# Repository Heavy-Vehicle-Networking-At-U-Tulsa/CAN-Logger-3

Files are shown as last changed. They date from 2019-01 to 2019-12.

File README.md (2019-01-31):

# CAN-Logger-3

An open source data logging system for heavy vehicle networks.

The docs folder contains schematics, gerber files, and Altium Designer source files. 

## Acknowledgements

This material is based upon work supported by the National Science Foundation under Grant No. 1715409. This project is in collaboration with the National Motor Freight Traffic Association (NMFTA).

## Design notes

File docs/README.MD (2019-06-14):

# CAN Logger 3 Documentation

## Errata
The original bill of materials uses the ATEEC608A-SSHCZ CryptoAuthentication chip from Microchip. This device is a SOIC 8 chip with single wire communicaitons. However, the schematic has the device connected as an I2C device. This chip should be replaced with the ATEEC608A-SSHDA-T device that used I2C communications.

Programmers must use ask for a non-disclosure agreement to get a data sheet for ATECC608A-SSHDA-T.

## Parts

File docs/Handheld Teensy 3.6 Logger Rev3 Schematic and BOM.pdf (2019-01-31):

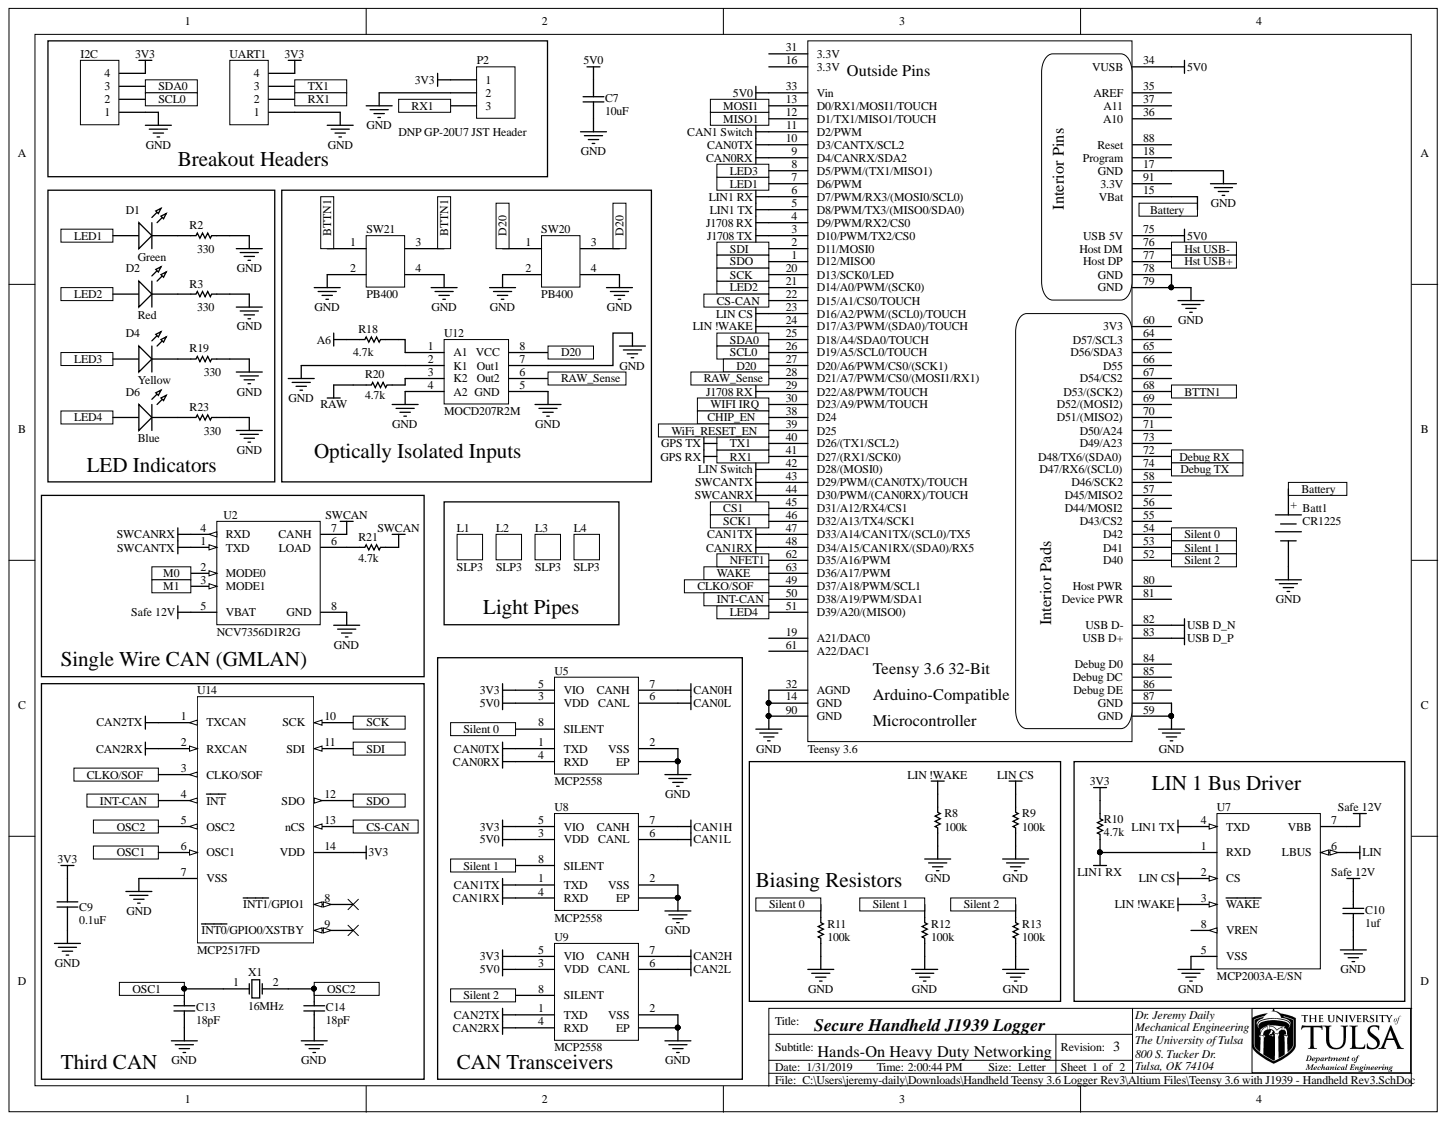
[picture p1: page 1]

GND
DNP GP-20U7 JST Header

Interior Pins Interior Pads

Single Wire CAN (GMLAN)

Title: Secure Handheld J1939 Logger | Dr. Jeremy Daily Mechanical Engineering The University of Tulsa 800 S. Tucker Dr. Tulsa, OK 74104

Hands-On Heavy Duty Networking Subtitle: | 3 Revision:

Date: 1/31/2019 Time: 2:00:44 PM Size: Letter | Sheet 1 of 2

C:\Users\jeremy-daily\Downloads\Handheld Teensy 3.6 Logger Rev3\Altium Files\Teensy 3.6 with J1939 - Handheld Rev3.SchDoc

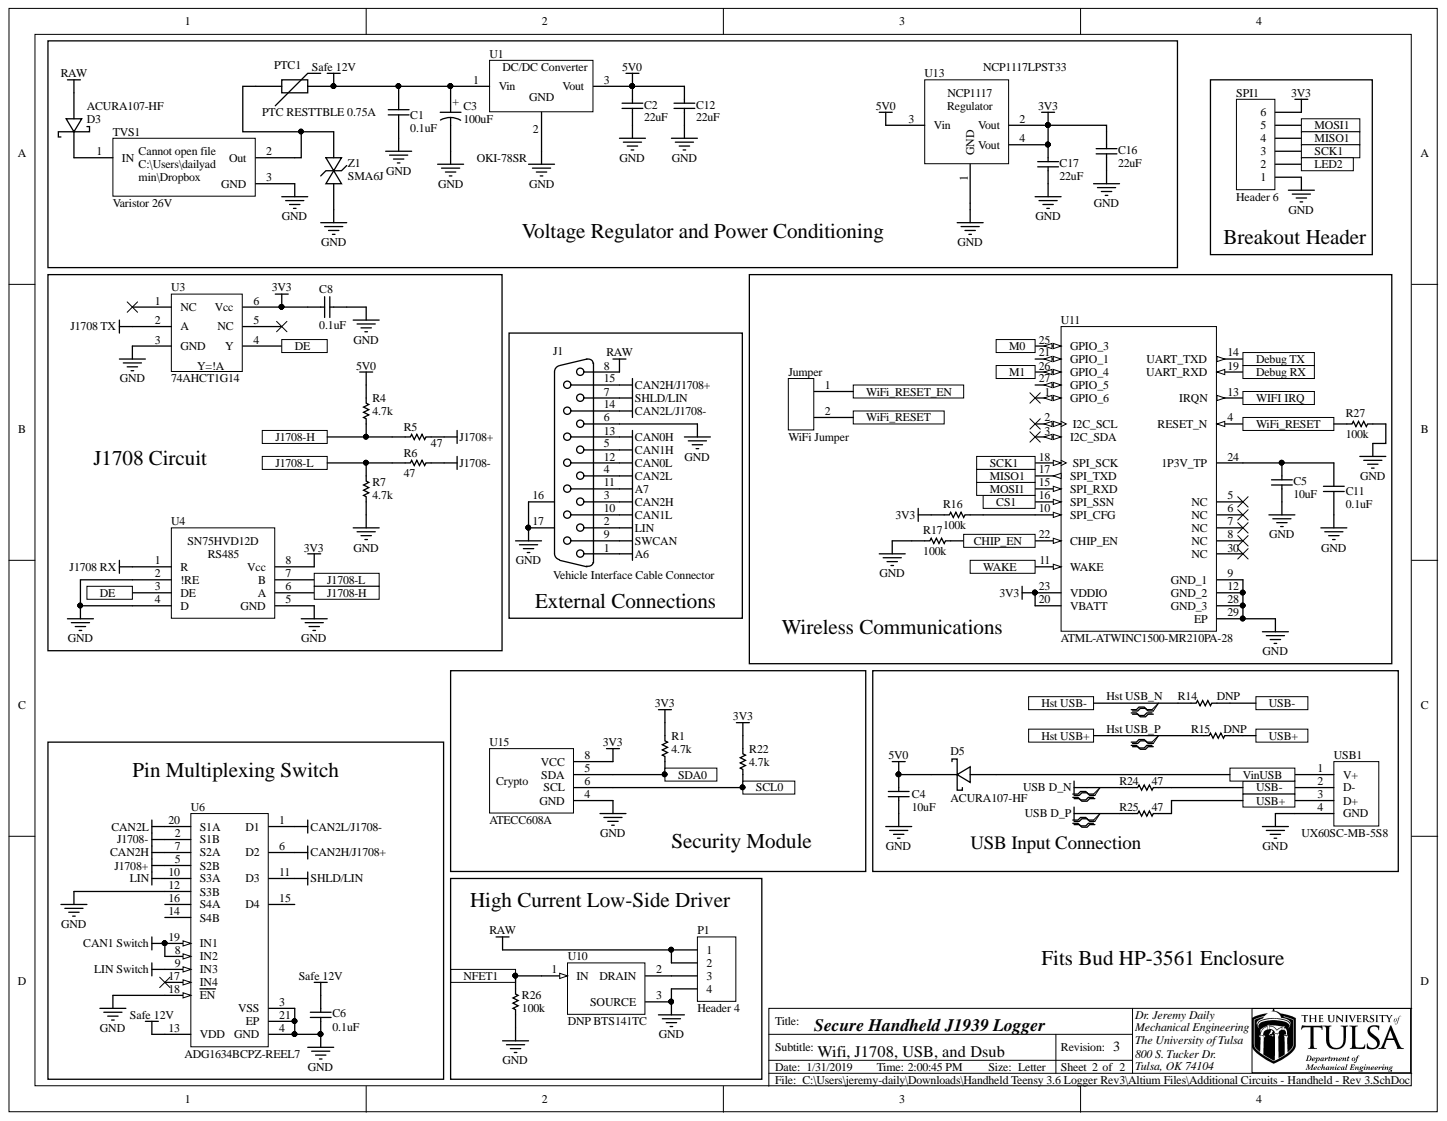
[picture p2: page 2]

Voltage Regulator and Power Conditioning

Vehicle Interface Cable Connector
External Connections

High Current Low-Side Driver

U10
IN 1 DRAIN | 2

Fits Bud HP-3561 Enclosure

Dr. Jeremy Daily
Mechanical Engineering
The University of Tulsa
800 S. Tucker Dr.
Tulsa, OK 74104

Subtitle:
C:\Users\jeremy-daily\Downloads\Handheld Teensy 3.6 Logger Rev3\Altium Files\Additional Circuits - Handheld - Rev 3.SchDoc

Item # | Quantity | Designator | Comment | Footprint | Description | Manufacturer | PartNumber | Supplier 1 | Supplier Part Num#beColr um1 n Name Error:Alte
1 | 1 | Batt1 | CR1225 | Battery Clip -CR1225 | Lithium Battery Non-Rechargeable (Primary) 3V Coin, 12.5mm | Linx | BAT-HLD-012-SMT | Digi-Key | BAT-HLD-012-SMT-ND
2 | 5 | C1, C6, C8, C9, C11 | 0.1uF | 0603 | CAP CER 0.1UF 50V X7R 0603, CAP CER 0.1UF 50V 10% X7R 0603 | KEMET | C0603C104K5RACAUTO | Digi-Key | 399-6856-1-ND
3 | 4 | C2, C12, C16, C17 | 22uF | 1206 | 22µF ±20% 25V Ceramic Capacitor X5R 1206 (3216 Metric) | Murata Electronics North America | GRT31CR61E226ME01L | Digi-Key | 490-12451-1-ND
4 | 1 | C3 | 100uF | Elec. Cap - G | Aluminum Electrolytic Capacitors Radial, Can - SMD 5000 Hrs @ 105°C | Panasonic Electronic Components | EEE-HC1H101P | Digi-Key | P19732CT-ND
5 | 3 | C4, C5, C7 | 10uF | 0603 | 10µF ±20% 25V Ceramic Capacitor X5R 0603 (1608 Metric) | Murata Electronics North America | ZRB18AR61E106ME01L | Digi-Key | 490-10991-1-ND
6 | 1 | C10 | 1uf | 0603 | 1µF ±20% 50V Ceramic Capacitor X5R 0603 (1608 Metric) | Murata Electronics North America | GRT188R61H105ME13D | Digi-Key | 490-12331-1-ND
7 | 2 | C13, C14 | 18pF | 0603 | 18pF ±5% 50V Ceramic Capacitor C0G, NP0 0603 (1608 Metric) | Kemet | C0603C180J5GACAUTO | Digi-Key | 399-16019-1-ND
8 | 1 | D1 | Green | 0805 Polarized | Green 570nm LED Indication - Discrete 2.2V 0805 (2012 Metric) | OSRAM Opto Semiconductors Inc. | LG R971-KN-1 | Digi-Key | 475-1410-1-ND
9 | 1 | D2 | Red | 0805 Polarized | Red 633nm LED Indication - Discrete 2V 0805 (2012 Metric) | OSRAM Opto Semiconductors Inc. | LS R976-NR-1 | Digi-Key | 475-1278-1-ND
10 | 2 | D3, D5 | ACURA107-HF | SMA with A and K | Diode Schottky 1000V 1A Surface Mount DO-214AC (SMA) | Comchip Technology | ACURA107-HF | Digi-Key | 641-1884-1-ND
11 | 1 | D4 | Yellow | 0805 Polarized | LED YELLOW DIFFUSED 0805 SMD | OSRAM Opto Semiconductors Inc. | LY R976-PS-36 | Digi-Key | 475-2560-1-ND
12 | 1 | D6 | Blue | 0805 Polarized | Blue 470nm LED Indication - Discrete 3.3V 0805 (2012 Metric) | Broadcom Limited | HSMN-C170 | Digi-Key | 516-1437-1-ND
13 | 3 | I2C, P1, UART1 | Header 4 | HDR1X4 | Header, 4-Pin
14 | 1 | J1 | Vehicle Interface Cable Connector | DSUB1.385-2H15 | Receptacle Assembly, 15 Position, Right Angle | Amphenol FCI | D15S33E4GV00LF | Digi-Key | 609-1498-ND
15 | 1 | Jumper | WiFi Jumper | WiFi Jumper
16 | 4 | L1, L2, L3, L4 | SLP3 | PCBComponent_1 | | Bivar Inc. | SLP3-150-250-R | Digi-Key | 492-2517-ND
17 | 1 | P2 | DNP GP-20U7 JST Header | MHDR1X3 | CONN HEADER PH SIDE 3POS 2MM SMD | JST | S3B-PH-SM4-TB(LF)(SN) | Digi-Key | 455-1750-1-ND
18 | 1 | PTC1 | PTC RESTTBLE 0.75A | 1812 | PTC RESTTBLE 0.75A 33V CHIP 1812 | Bel Fuse Inc. | 0ZCG0075BF2B | Digi-Key | 507-1765-1-ND
19 | 8 | R1, R4, R7, R10, R18, R20, R21, R22 | 4.7k | 0603 | ±1% 0.1W, 1/10W Chip Resistor 0603 (1608 Metric) Automotive AEC-Q200, High Voltage Thick Film | Rohm Semiconductor | KTR03EZPF4701 | Digi-Key | RHM4.7KAYCT-ND
20 | 4 | R2, R3, R19, R23 | 330 | 0603 | 330 Ohms ±1% 0.1W, 1/10W Chip Resistor 0603 (1608 Metric) Automotive AEC-Q200, High Voltage Thick Film | Rohm Semiconductor | KTR03EZPF3300 | Digi-Key | RHM330AYCT-ND
21 | 4 | R5, R6, R24, R25 | 47 | 0603 | ±1% 0.1W, 1/10W Chip Resistor 0603 (1608 Metric) Automotive AEC-Q200, High Voltage Thick Film | Rohm Semiconductor | KTR03EZPF47R0 | Digi-Key | RHM47AYCT-ND
22 | 9 | R8, R9, R11, R12, R13, R16, R17, R26, R27 | 100k | 0603 | ±1% 0.1W, 1/10W Chip Resistor 0603 (1608 Metric) Automotive AEC-Q200, High Voltage Thick Film | Rohm Semiconductor | KTR03EZPF1003 | Digi-Key | RHM100KAYCT-ND
23 | 2 | R14, R15 | DNP | 0603 | RES SMD 47 OHM 1% 1/10W 0603 | Panasonic Electronic Components | ERJ-3EKF47R0V | Digi-Key | P47.0HCT-ND
24 | 1 | SPI1 | Header 6 | HDR1X6 | Header, 6-Pin
25 | 2 | SW20, SW21 | PB400 | PB400 | Pushbutton Switch DPST-NO Standard Through Hole, Right Angle | E-Switch | PB400OAQR1BLK | Digi-Key | EG5548-ND
26 | 1 | Teensy 3.6 | Teensy 3.6 | Teensy 3.6 Surface Mount | K66 Teensy 3.6 Kinetis MCU 32-Bit ARM® Cortex®-M4 Embedded Evaluation Board | PRJC | Teensy 3.6 | Digi-Key | 1568-1442-ND
27 | 1 | TVS1 | Varistor 26V | Transfeed | 34.5V 80A Varistor 1 Circuit Surface Mount 0805 (2012 Metric) | AVX | V2AF126C600Y2EDP | Digi-Key | 478-10038-1-ND
28 | 1 | U1 | OKI-78SR | OKI-78SR | 5V DC/DC Converter (7805 replacement) | Murata Power Solutions Inc. | OKI-78SR-5/1.5-W36H-C | Digi-Key | 811-2692-ND
29 | 1 | U2 | NCV7356D1R2G | ONSC-SOIC-8-751-07_V | Single Wire CAN Transceiver, 5 to 27 V, 8-Pin SOIC, Pb-Free, Tube | On Semiconductor | NCV7356D1R2G | Digi-Key | NCV7356D1R2GOSCT-ND
30 | 1 | U3 | 74AHCT1G14 | SOT-353 | IC SCHMIT-TRIGG INV GATE SOT353 | Diodes Incorporated | 74AHCT1G14SE-7 | Digi-Key | 74AHCT1G14SE-7DICT-ND
31 | 1 | U4 | SN75HVD08DR | SOIC-SN8_N | IC RS485 TXRX 3/5V 8-SOIC | Texas Instruments | SN75HVD08DR | Digi-Key | 296-37893-1-ND
32 | 3 | U5, U8, U9 | MCP2558 | TDFN | Microchip CAN FD Transceiver with Silent Mode | Microchip Technology, Microchip | MCP2558FDT-H/MNY | Digi-Key | MCP2558FDT-H/MNYCT-ND
33 | 1 | U6 | ADG1634BCPZ-REEL7 | ADI-CP-20-4_N | IC SWITCH QUAD SPDT 20LFCSP | Analog Devices | ADG1634BCPZ-REEL7 | Digi-Key | ADG1634BCPZ-REEL7CT-ND
34 | 1 | U7 | MCP2003A-E/SN | SOIC-SN8_N | LIN J2602 Transceiver, 8-Pin SOIC, Extended Temperature, Tape and Reel | Microchip Technology | MCP2003A-E/SN | Digi-Key | MCP2003A-E/SN-ND
35 | 1 | U10 | DNP BTS141TC | INF-PG-TO263-3-2_N | Smart Low-Side Power Switch HITFET, 60 V VDS, 12 A ID, -40 to 150 degC, PG-TO263-3-2, Reel, Green | Infineon | BTS141TCBUMA1 | Digi-Key | BTS141TCBUMA1CT-ND
36 | 1 | U11 | ATML-ATWINC1500-MR210PA-28 | ATML-ATWINC1500-MR210PA-28_V | SMARTCONNECT ATWINC1500B-MU-T MO | Microchip Technologies | ATWINC1510-MR210PB1140 | Digi-Key | ATWINC1510-MR210PB1140-
ND
37 | 1 | U12 | MOCD207R2M | SOIC-8 | Optoisolator Transistor Output 2500Vrms 2 Channel 8-SO Tall | Fairchild/ON Semiconductor | MOCD207R2M | Digi-Key | MOCD207R2MCT-ND
38 | 1 | U13 | NCP1117LPST33 | SOT-223 | Linear Voltage Regulator IC Positive Fixed Output 3.3V 1A SOT-223 | On Semiconductor | NCP1117LPST33T3G | Digi-Key | NCP1117LPST33T3GOSCT-
ND
39 | 1 | U14 | MCP2517FD | SOP14 | CANbus Controller CAN 2.0 SPI Interface 14-VDFN (4.5x3) | Microchip Technology | MCP2517FDT-H/JHA | Digi-Key | MCP2517FDT-H/JHACT-ND
40 | 1 | U15 | ATECC608A | SOIC-8 | Authentication Chip IC Networking and Communications 8-SOIC | Microchip Technology | ATECC608A-SSHCZ-T | Digi-Key | ATECC608A-SSHCZ-TCT-ND
41 | 1 | USB1 | UX60SC-MB-5S8 | USB Mini UX60S | USB - mini B USB 2.0 Receptacle Connector 5 Position Surface Mount, Right Angle; Through Hole | Hirose | UX60SC-MB-5S8 | Digi-Key | H11589CT-ND
42 | 1 | X1 | 16MHz | XTAL 2 pad | CRYSTAL 16MHZ 18PF SMD | TXC CORPORATION | 7A-16.000MAAJ-T | Digi-Key | 887-1086-1-ND
43 | 1 | Z1 | SMA6J | SMA | TVS DIODE 20VWM 36.8VC SMA | Micro Commercial Co | SMA6J24CA-TP | Digi-Key | SMA6J24CA-TPMSCT-ND

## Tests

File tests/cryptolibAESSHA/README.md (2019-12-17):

# Arduino Test Code for Hardware Encryption
This sketch and supporting files leverages the on-board memory mapped cryptographic acceleration unit (mmCAU) in the Teensy 3.6. The files used in here were derived or copied from three sources:

  1. The idea for the test code came from https://github.com/manitou48/teensy3/blob/master/cryptolib.ino
  2. CAUAP: Crypto Acceleration Unit: CAU and mmCAU software library https://www.nxp.com/products/processors-and-microcontrollers/additional-processors-and-mcus/coldfire-plus-coldfire/crypto-acceleration-unit-cau-and-mmcau-software-li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
  3. To make the library calls compativble with Arduino, use the header file from https://github.com/PaulStoffregen/CryptoAccel

The test code determines the speed by which a block of 512 bytes can be encrypted. 

Note: this sketch does not randomize the initialization vector or AES key and should not be used to protect anything.

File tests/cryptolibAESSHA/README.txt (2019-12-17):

This is an updated release of the Kinetis MMCAU security function library.

This release:

  - new asm-cm0p library created, optimized for ARMv6-M ISA
  - minor improvements to asm-cm4 library, optimized for ARMv7-M ISA

This release contains the following structure for the mmcau directory:

README.txt (this file)

asm-cm0p
|-- cau_api.h
|-- lib_mmcau-cm0p.a
|-- lst
|   |-- mmcau_aes_functions.lst
|   |-- mmcau_des_functions.lst
|   |-- mmcau_md5_functions.lst
|   |-- mmcau_sha1_functions.lst
|   `-- mmcau_sha256_functions.lst
`-- src
    |-- cau2_defines.hdr
    |-- mmcau_aes_functions.s
    |-- mmcau_des_functions.s
    |-- mmcau_md5_functions.s
    |-- mmcau_sha1_functions.s
    `-- mmcau_sha256_functions.s

asm-cm4
|-- cau_api.h
|-- lib_mmcau.a
|-- lst
|   |-- mmcau_aes_functions.lst
|   |-- mmcau_des_functions.lst
|   |-- mmcau_md5_functions.lst
|   |-- mmcau_sha1_functions.lst
|   `-- mmcau_sha256_functions.lst
`-- src
    |-- cau2_defines.hdr
    |-- mmcau_aes_functions.s
    |-- mmcau_des_functions.s
    |-- mmcau_md5_functions.s
    |-- mmcau_sha1_functions.s
    `-- mmcau_sha256_functions.s

Each mmcau optimized assembly library (cm0p, cm4) is contained in 5
files (18 functions) and is archived in a lib_mmcau*.a file.

Each library was assembled with:
GNU assembler version 4.3.3 (arm-none-linux-gnueabi-as)

This mmcau library update is checked-in under Design Sync:
sync://sync-15010:15010/Projects/mcp_armp/mmcau_apb3/tool_data/lib/
tagged as: mmcau_apb3.01.00.00.11

asm-cm0p : mmcau assembly library optimized for the ARMv6-M ISA
********

Includes the following file versions (with checkin timestamps): 

12/19/2013 10:01    1.1     cau_api.h
05/04/2015 11:30    1.2     lib_mmcau-cm0p.a
                            (checked in as lib_mmcau-v6m.a)
08/22/2010 22:52    1.1     cau2_defines.hdr
10/31/2013 12:21    1.1     mmcau_aes_functions.s
10/31/2013 12:21    1.1     mmcau_des_functions.s
10/31/2013 12:21    1.1     mmcau_md5_functions.s
05/04/2015 10:09    1.2     mmcau_sha1_functions.s
11/20/2013 09:27    1.2     mmcau_sha256_functions.s

The following additional asm listing files not under revision control are
also included (with last modified timestamps):

11/19/2013 11:36            mmcau_aes_functions.lst
11/19/2013 11:36            mmcau_des_functions.lst
11/19/2013 11:36            mmcau_md5_functions.lst
03/31/2015 07:56            mmcau_sha1_functions.lst
11/19/2013 11:36            mmcau_sha256_functions.lst

asm-cm4 : mmcau assembly library optimized for the ARMv7-M ISA
*******

Includes the following file versions (with checkin timestamps): 

12/19/2013 10:01    1.1     cau_api.h
11/21/2013 13:41    1.6     lib_mmcau.a
08/22/2010 22:52    1.1     cau2_defines.hdr
11/21/2013 13:17    1.4     mmcau_aes_functions.s
11/21/2013 13:17    1.4     mmcau_des_functions.s
11/21/2013 13:17    1.6     mmcau_md5_functions.s
11/21/2013 13:17    1.5     mmcau_sha1_functions.s
11/21/2013 13:18    1.6     mmcau_sha256_functions.s

The following additional asm listing files not under revision control are
also included (with last modified timestamps):

11/21/2013 13:23            mmcau_aes_functions.lst
11/21/2013 13:23            mmcau_des_functions.lst
11/21/2013 13:23            mmcau_md5_functions.lst
11/21/2013 13:23            mmcau_sha1_functions.lst
11/21/2013 13:23            mmcau_sha256_functions.lst

The calling conventions for the mmcau functions are as follows:
---------------------------------------------------------------

mmcau_aes_functions:
    void    mmcau_aes_set_key (const unsigned char *key,
                               const int key_size,
                               unsigned char *key_sch)
    void    mmcau_aes_encrypt (const unsigned char *in,
                               const unsigned char *key_sch,
                               const int nr,
                               unsigned char *out)
    void    mmcau_aes_decrypt (const unsigned char *in,
                               const unsigned char *key_sch,
                               const int nr,
                               unsigned char *out)

mmcau_des_functions:
    int     mmcau_des_chk_parity (const unsigned char *key)
    void    mmcau_des_encrypt (const unsigned char *in,
                               const unsigned char *key,
                               unsigned char *out)
    void    mmcau_des_decrypt (const unsigned char *in,
                               const unsigned char *key,
                               unsigned char *out)

mmcau_md5_functions:
    void    mmcau_md5_initialize_output (const unsigned char *md5_state)
    void    mmcau_md5_hash_n (const unsigned char *msg_data,
                              const int num_blks,
                              unsigned char *md5_state)
    void    mmcau_md5_update (const unsigned char *msg_data,
                              const int num_blks,
                              unsigned char *md5_state)
    void    mcau_md5_hash    (const unsigned char *msg_data,
                              unsigned char *md5_state)

mmcau_sha1_functions:
    void    mmcau_sha1_initialize_output (const unsigned int *sha1_state)
    void    mmcau_sha1_hash_n (const unsigned char *msg_data,
                               const int num_blks,
                               unsigned int *sha1_state)
    void    mmcau_sha1_update (const unsigned char *msg_data,
                               const int num_blks,
                               unsigned int *sha1_state)
    void    mmcau_sha1_hash   (const unsigned char *msg_data,
                               unsigned int *sha1_state)

mmcau_sha256_functions:
    int     mmcau_sha256_initialize_output (const unsigned int *output)
    void    mmcau_sha256_hash_n (const unsigned char *input,
                                 const int num_blks,
                                 unsigned int *output)
    void    mmcau_sha256_update (const unsigned char *input,
                                 const int num_blks,
                                 unsigned int *output)
    void    mmcau_sha256_hash   (const unsigned char *input,
                                 unsigned int *output)

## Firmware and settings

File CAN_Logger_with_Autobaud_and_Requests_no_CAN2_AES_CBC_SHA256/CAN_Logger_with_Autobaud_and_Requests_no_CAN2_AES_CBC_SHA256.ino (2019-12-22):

/*
 * NMFTA CAN Logger 3 Project   
 * 
 * Arduino Sketch for the CAN Logger 3 to record up to 3 CAN channels using
 * a Teensy 3.6. See https://github.com/Heavy-Vehicle-Networking-At-U-Tulsa/CAN-Logger-3
 * for more details.
 * 
 * Written By Dr. Jeremy S. Daily
 * The University of Tulsa
 * Department of Mechanical Engineering
 * 
 * 18 Nov 2018
 * 
 * Released under the MIT License
 *
 * Copyright (c) 2018        Jeremy S. Daily
 *
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
 * 
 * This program logs data to a binary file.  
 * 
 * Samples are logged at regular intervals.  The maximum logging rate
 * depends on the quality of your SD card. 
 * 
 * Much of this sketch was inspired by the examples from https://github.com/greiman/SdFs
 * 
 * The program makes use of the SdFs library
 * 
 */


//included libraries 
#include <SdFs.h>  // access the SD Card
#include <FlexCAN.h> // Access the CAN network.
#include <OneButton.h> // Handle the buttons
#include <TimeLib.h> // be able to keep realtime.
#include <EEPROM.h> // Use this to keep track of the file names 
#include <error.h> // Include definitions to help understand CAN errors.
#include <FastCRC.h> // Add the CRC to include in the record to validate CAN frame messages.
#include <sha256.h> // Keep track of the file hash as it is created.
#include "CryptoAccel.h" //Makes the cryptographic acceleration hardware arduino compatible

//Get access to a hardware based CRC32 
FastCRC32 CRC32;

// define the number of rounds with AES encryption.
#define AES_128_NROUNDS 10

// EEPROM memory addresses for creating file names
// The Address 0 and 1 are used for baud rates
#define EEPROM_DEVICE_ID_ADDR  4  // 5, 6, 7=00
#define EEPROM_FILE_ID_ADDR    8  // 9, 10, 11 ==00
#define EEPROM_BRAND_NAME_ADDR 12 //13 and 14 ==00


#define CRC32_BUFFER_LOC       508

// Setup a limit to turn off the CAN controller after this many messages.
#define ERROR_COUNT_LIMIT 5000

// setup the length for a serial command buffer to control the logger 2.
#define COMMAND_BUFFER_LEN 20 
char command_buffer[COMMAND_BUFFER_LEN];

// Set up the SD Card object
SdFs sd;

#define SD_CONFIG SdioConfig(FIFO_SDIO)

// Create a file object
FsFile binFile;
FsFile baudFile;

String directory_listing;

// All CAN messages are received in the FlexCAN structure
CAN_message_t rxmsg,txmsg;

// Define CAN TXRX Transmission Silent pins
// See the CAN Logger 2 Schematic for the source pins
#define SILENT_0   42
#define SILENT_1   41
#define SILENT_2   40
#define BUTTON_PIN 20
#define POWER_PIN  21

// Use the button for multiple inputs: click, doubleclick, and long click.
OneButton button(BUTTON_PIN, true);

String commandString;

/*  code to process time sync messages from the serial port   */
char timeString[100];
char iv_string[16];

// define a counter to reset after each second is counted.
elapsedMicros microsecondsPerSecond;
elapsedMicros micro_timer;
// Get a uniqueName for the Logger File
char logger_name[4];
bool file_open;
char current_file_name[13];
char prefix[5];
char file_name_prefix[6];
char brand_name[3];

//variables for the CAN Message
uint32_t rxId;
uint8_t len;
uint8_t rxBuf[8];
uint8_t ext_flag;

#define FAST_BLINK_TIME 50 //milliseconds
#define SLOW_BLINK_TIME 500 //milliseconds

//Setup LEDs
#define GREEN_LED 6
#define RED_LED 14
#define YELLOW_LED 5

boolean GREEN_LED_state;
boolean RED_LED_state;
boolean YELLOW_LED_state;

elapsedMillis GREEN_LED_Slow_Timer;
elapsedMillis RED_LED_Slow_Timer;
elapsedMillis YELLOW_LED_Slow_Timer;

elapsedMillis GREEN_LED_Fast_Timer;
elapsedMillis RED_LED_Fast_Timer;
elapsedMillis YELLOW_LED_Fast_Timer;

boolean GREEN_LED_slow_blink_state;
boolean RED_LED_slow_blink_state;
boolean YELLOW_LED_slow_blink_state;

boolean GREEN_LED_fast_blink_state;
boolean RED_LED_fast_blink_state;
boolean YELLOW_LED_fast_blink_state;


// Setup a counter to keep track of the filename
char current_file[4];

// Keep track of the CAN Channel (0, 1)
uint8_t current_channel;


// There are 2 data buffers that get switched. We need to know which one
// we are using and where we are in the buffer.
#define CAN_FRAME_SIZE 25
#define MAX_MESSAGES 19
#define BUFFER_POSITION_LIMIT (CAN_FRAME_SIZE * MAX_MESSAGES)
#define BUFFER_SIZE 512
uint8_t data_buffer[BUFFER_SIZE];
uint16_t current_position;

//Counter and timer to keep track of transmitted messages
#define TX_MESSAGE_TIME 2 //milliseconds
uint32_t TXCount0 = 0;
uint32_t TXCount1 = 0;
uint32_t TXCount2 = 0;
elapsedMillis TXTimer0;
elapsedMillis TXTimer1;
elapsedMillis TXTimer2;

// To use a button to send requests, we need to track it.
#define NUM_REQUEST_PASSES 3
#define REQUEST_TIMING 250 //milliseconds
elapsedMillis send_request_timer;
elapsedMillis send_iso_request_timer;
boolean send_requests;
boolean send_iso_requests;
uint16_t request_index;
uint16_t iso_request_index;
uint8_t send_passes;
uint8_t send_iso_passes;

#define NUM_REQUESTS 27
uint16_t request_pgn[NUM_REQUESTS] = {
  65261, // Cruise Control/Vehicle Speed Setup
  65214, // Electronic Engine Controller 4
  65259, // Component Identification
  65242, // Software Identification
  65244, // Idle Operation
  65260, // Vehicle Identification
  65255, // Vehicle Hours
  65253, // Engine Hours, Revolutions
  65257, // Fuel Consumption (Liquid)
  65256, // Vehicle Direction/Speed
  65254, // Time/Date
  65211, // Trip Fan Information
  65210, // Trip Distance Information
  65209, // Trip Fuel Information (Liquid)
  65207, // Engine Speed/Load Factor Information
  65206, // Trip Vehicle Speed/Cruise Distance Information
  65205, // Trip Shutdown Information
  65204, // Trip Time Information 1
  65200, // Trip Time Information 2
  65250, // Transmission Configuration
  65203, // Fuel Information (Liquid)
  65201, // ECU History
  65168, // Engine Torque History
  64981, // Electronic Engine Controller 5
  64978, // ECU Performance
  64965, // ECU Identification Information
  65165  // Vehicle Electrical Power #2
};

#define NUM_ISO_REQUESTS 9
uint16_t iso_request[NUM_ISO_REQUESTS] = {
  0xF195, //System Supplier ECU Software Version Number
  0xF190, //Vehicle Identfication Number
  0xF193, //System Supplier ECU Hardware Version Number
  0xF18C, //ECU Serial Number
  0xF180, //Boot Software Identfication
  0xF181, //Application Software Identfication
  0xF186, //Active Diagnostic Session
  0xF192, //System Supplier ECU Hardware Number
  0xF197, //System Name or Engine Type
};
    
//Create a counter and timer to keep track of received message traffic
#define RX_TIME_OUT 1000 //milliseconds
elapsedMillis RXTimer;
uint32_t RXCount0 = 0;
uint32_t RXCount1 = 0;
uint32_t RXCount2 = 0;
elapsedMillis lastCAN0messageTimer;
elapsedMillis lastCAN1messageTimer;
elapsedMillis lastCAN2messageTimer;
uint32_t ErrorCount0 = 0;
uint32_t ErrorCount1 = 0;
//uint32_t ErrorCount2 = 0;

// Should we stream the CAN frame to the serial port? Serial 
// can't keep up with heavy CAN bus loads, so this is default to false.
bool stream = false;

// Track the state of the user's desire to log. This can toggle based 
// on user input.
bool recording = true;

//SHA256
unsigned int hash_counter;
#define SHA256_BLOCK_SIZE 32          // SHA256 outputs a 32 byte digest
byte hash_text[SHA256_BLOCK_SIZE*2];
byte hash[SHA256_BLOCK_SIZE];
byte before_closing_hash[BUFFER_SIZE];
boolean first_buffer_sent;
Sha256* sha256Instance;
#define SHA_UPDATE_SIZE 50

// random RNG
#define REPS 50

#define RNG_CR_GO_MASK        0x1u
#define RNG_CR_HA_MASK        0x2u
#define RNG_CR_INTM_MASK      0x4u
#define RNG_CR_CLRI_MASK      0x8u
#define RNG_CR_SLP_MASK       0x10u
#define RNG_SR_OREG_LVL_MASK  0xFF00u
#define RNG_SR_OREG_LVL_SHIFT 8
#define RNG_SR_OREG_LVL(x)    (((uint32_t)(((uint32_t)(x))<<RNG_SR_OREG_LVL_SHIFT))&RNG_SR_OREG_LVL_MASK)
#define SIM_SCGC6_RNGA        ((uint32_t)0x00000200)

uint32_t random_number;
uint8_t iv_and_key[32];

uint32_t trng(){
    RNG_CR |= RNG_CR_GO_MASK;
    while((RNG_SR & RNG_SR_OREG_LVL(0xF)) == 0); // wait
    return RNG_OR;
}

    
unsigned char cipher_text[BUFFER_SIZE];
unsigned char aeskey[16], keysched[4 * 44], in[16], out[16], init_vector[16];

//Generate ranndom iv and key function, 32 bytes number
void iv_key_RNG(){
    
    for (int m =0;m<8;m++){
    SIM_SCGC6 |= SIM_SCGC6_RNGA; // enable RNG
    RNG_CR &= ~RNG_CR_SLP_MASK;
    RNG_CR |= RNG_CR_HA_MASK;  // high assurance, not needed

    //Random number, 4 byte long
    for (int l =0;l<REPS;l++){
      random_number = trng();
      }
    iv_and_key[4*m] = (random_number & 0xFF000000) >> 24;
    iv_and_key[4*m+1] = (random_number & 0x00FF0000) >> 16;
    iv_and_key[4*m+2] = (random_number & 0x0000FF00) >> 8;
    iv_and_key[4*m+3] = (random_number & 0x000000FF);
    }
}

//AES CBC funtion
void aes_cbc_encrypt(const unsigned char *data, unsigned char *cipher_text){
  //Data length should be a multiple of 16 bytes
  // Need to initialize out with the initialization vector
  for (uint32_t j=0; j < BUFFER_SIZE; j+=16){
    for (uint8_t i = 0; i < 16; i++){
      in[i] = data[j+i] ^ out[i];
    }
    mmcau_aes_encrypt (in, keysched, AES_128_NROUNDS, out); // # 16-byte block
    memcpy(&cipher_text[j],out,16);
  }
}


/*
 * The load_buffer() function maps the received CAN message into
 * the positions in the buffer to store. Each buffer is 512 bytes.
 * 20 CAN messages can fit in the buffer since they are 25 bytes long.
 * Note: an additional channel byte was added when comparing to the 
 * NMFTA CAN Logger 1 files. 
 * 
 * Use this function to understand how the the binary file format was created.
 * When reading the binary, be sure to read it in 512 byte chunks.
 */
void load_buffer(){
  //SHA256 last buffer
  if (first_buffer_sent){
    micro_timer=0;
    if ((current_position - 4) % 50 == 0){ // use 50 because it represents 2 messages.
      if (hash_counter < 8){
        for (int z =0;z<SHA_UPDATE_SIZE;z++){
          hash_text[z]=cipher_text[hash_counter*SHA_UPDATE_SIZE + z];
        }
        sha256Instance->update(hash_text,SHA_UPDATE_SIZE);
        Serial.print("Time to hash 64 bytes (us):");
        Serial.println(micro_timer);
        hash_counter++;
      }
    }
  }


  // reset the timer
  RXTimer = 0;

  //Toggle the LED
  GREEN_LED_state = !GREEN_LED_state;
  digitalWrite(GREEN_LED, GREEN_LED_state);
    
  data_buffer[current_position] = current_channel;
  current_position += 1;
  
  time_t timeStamp = now();
  memcpy(&data_buffer[current_position], &timeStamp, 4);
  current_position += 4;
  
  memcpy(&data_buffer[current_position], &rxmsg.micros, 4);
  current_position += 4;

  memcpy(&data_buffer[current_position], &rxmsg.id, 4);
  current_position += 4;

  // Store the message length as the most significant byte and use the 
  // lower 24 bits to store the microsecond counter for each second.
  uint32_t DLC = (rxmsg.len << 24) | (0x00FFFFFF & uint32_t(microsecondsPerSecond));
  memcpy(&data_buffer[current_position], &DLC, 4);
  current_position += 4;

  memcpy(&data_buffer[current_position], &rxmsg.buf, 8); 
  current_position += 8;

  if ((rxmsg.id & CAN_ERR_FLAG) == CAN_ERR_FLAG){
    RED_LED_state = !RED_LED_state;
    digitalWrite(RED_LED, RED_LED_state);  
  }
  
  // Check the current position and see if the buffer needs to be written 
  // to the SD card.
  check_buffer();
}
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
void loop(void) {
  // monitor the CAN channels
  if (Can0.read(rxmsg)){
    RXCount0++;
    current_channel = 0;
    rx_message_routine(RXCount0);
  }
  if (Can1.read(rxmsg)){
    RXCount1++;
    current_channel = 1;
    rx_message_routine(RXCount1);
  }
  /*if (Can2.readMsgBuf(&rxId, &ext_flag, &len, rxBuf) == CAN_OK){
    RXCount2++;
    memcpy(&rxmsg.buf, rxBuf, 8);
    rxmsg.len = uint8_t(len);
    rxmsg.id = uint32_t(rxId);
    current_channel = 2;
    rx_message_routine(RXCount2);
  } */

  // Close the file if messages stop showing up.
  if (RXTimer >= RX_TIME_OUT && file_open){
    close_binFile();
    RXTimer = 0;
  }
  
  led_blink_routines();
  
  // Send requests for additional data if needed
  if (send_requests){
    if (send_passes < NUM_REQUEST_PASSES){
      if (send_request_timer > REQUEST_TIMING){
        send_request_timer = 0;
        txmsg.len = 3;
        txmsg.id = 0x18EAFFF9;
        txmsg.buf[0] = (request_pgn[request_index] & 0x0000FF);
        txmsg.buf[1] = (request_pgn[request_index] & 0x00FF00) >> 8 ;
        txmsg.buf[2] = (request_pgn[request_index] & 0xFF0000) >> 16; //These are in reverse byte order.
        send_Can0_message(txmsg);
        if (RXCount1 > 0) send_Can1_message(txmsg);
        //if (RXCount2 > 0) send_Can2_message(txmsg);
        //Toggle LED light as messages are sent
        RED_LED_state = !RED_LED_state;                       
        digitalWrite(RED_LED,RED_LED_state);  
        request_index++;
        if (request_index >= NUM_REQUESTS) {
          request_index = 0;
          send_passes++;
          //shuffle
          //Serial.println("Shuffling Requests");
          for (int i = 0; i < NUM_REQUESTS; i++) {
            int j = random(i, NUM_REQUESTS);
            auto temp = request_pgn[i];
            request_pgn[i] = request_pgn[j];
            request_pgn[j] = temp;
          }
        }
      }
    }
    else
    {
      send_passes = 0;
      send_requests = false;
      send_iso_requests = true;
      send_iso_request_timer = 0;
    }
  }
  else if (send_iso_requests)
  {
    if (send_iso_passes < NUM_REQUEST_PASSES){
      if (send_iso_request_timer > REQUEST_TIMING){
        send_iso_request_timer = 0;
        txmsg.len = 8;
        txmsg.id = 0x18DAFFF9;
        txmsg.buf[0] = 0x02;
        txmsg.buf[1] = (iso_request[request_index] & 0x00FF) >> 0 ;
        txmsg.buf[2] = (iso_request[request_index] & 0xFF00) >> 8; //These are in reverse byte order.
        send_Can0_message(txmsg);
        if (RXCount1 > 0) send_Can1_message(txmsg); //only send something if the network is alive
        //if (RXCount2 > 0) send_Can2_message(txmsg); //only send something if the network is alive
        //Toggle LED light as messages are sent
        RED_LED_state = !RED_LED_state;                       
        digitalWrite(RED_LED,RED_LED_state);  
        request_index++;
        if (request_index >= NUM_ISO_REQUESTS) {
          request_index = 0;
          send_iso_passes++;
          //shuffle
          //Serial.println("Shuffling Requests");
          for (int i = 0; i < NUM_ISO_REQUESTS; i++) {
            int j = random(i, NUM_ISO_REQUESTS);
            auto temp = iso_request[i];
            iso_request[i] = request_pgn[j];
            iso_request[j] = temp;
          }
        }
      }
    }
    else
    {
      send_iso_passes = 0;
      send_iso_requests = false;
    }
  }
  
  if (Serial.available() >= 2) {
    commandString = Serial.readStringUntil('\n');
    commandString.toCharArray(command_buffer, COMMAND_BUFFER_LEN);
    // Count the number of valid characters
    uint8_t j = 0;
    while ((isAlphaNumeric(command_buffer[j]) or command_buffer[j] == ' ') and j < COMMAND_BUFFER_LEN) j++;
    if (commandString.length() == j){ // check to make sure no non-ascii inputs are being interpreted 
      memset(command_buffer,0,COMMAND_BUFFER_LEN);
      if      (commandString.equalsIgnoreCase("HEX"))        print_hex();
      else if (commandString.equalsIgnoreCase("BIN"))        stream_binary(current_file_name);
      else if (commandString.equalsIgnoreCase("STOP"))       turn_recording_off();
      else if (commandString.equalsIgnoreCase("START"))      turn_recording_on();
      else if (commandString.equalsIgnoreCase("NEW"))        close_binFile();
      else if (commandString.equalsIgnoreCase("DF"))         sd_capacity();
      else if (commandString.equalsIgnoreCase("LS"))         list_files();
      else if (commandString.equalsIgnoreCase("LS A"))       list_files_a();
      else if (commandString.equalsIgnoreCase("FORMAT"))     format_sd_card();
      else if (commandString.equalsIgnoreCase("BAUD"))       display_baud_rate();
      else if (commandString.equalsIgnoreCase("ERRORS"))     display_error_count();
      else if (commandString.equalsIgnoreCase("STREAM ON"))  turn_streaming_on();
      else if (commandString.equalsIgnoreCase("STREAM OFF")) turn_streaming_off();
      else if (commandString.equalsIgnoreCase("REQUEST ON")) turn_requests_on();
      else if (commandString.equalsIgnoreCase("REQUEST OFF"))turn_requests_off();
      else if (commandString.startsWith("DEL ")){
        char delete_file_name[13];
        commandString.remove(0,4);
        commandString.toCharArray(delete_file_name,13);
        delete_file(delete_file_name);
      }
      else if (commandString.equalsIgnoreCase("BAUDRATE")){
        char stream_file_name[13]; 
        strcpy(stream_file_name,"baudRate.txt");
        stream_text(stream_file_name);
      }
      else if (commandString.startsWith(brand_name)){
        char stream_file_name[13]; 
        commandString.toCharArray(stream_file_name,13);
        stream_binary(stream_file_name);     
      }
      else if (commandString.startsWith("ID ")){
        commandString.remove(0,3);
        if (commandString.length() == 3){
          commandString.toUpperCase();
          commandString.toCharArray(logger_name,4);
          EEPROM.put(EEPROM_DEVICE_ID_ADDR,logger_name);
          Serial.print("Set Device ID to ");
          Serial.println(logger_name);
        }
        else {
          Serial.println("Improper ID Length");
        }
      }
      else if (commandString.startsWith("COUNT")){
        commandString.remove(0,6);
        commandString.toUpperCase();
        char input_count[4];
        commandString.toCharArray(input_count,4);
        memset(current_file,0,4);
        memset(current_file,'0',3);
        if (commandString.length() == 3) {
          current_file[0] = input_count[0];
          current_file[1] = input_count[1];
          current_file[2] = input_count[2];
        }
        else if (commandString.length() == 2){
          current_file[1] = input_count[0];
          current_file[2] = input_count[1];
        }
        else if (commandString.length() == 1){
          current_file[2] = input_count[0];
        }
        if (isFileNameValid(current_file)){
          EEPROM.put(EEPROM_FILE_ID_ADDR,current_file);
          Serial.print("Set current file to ");
          Serial.println(current_file);
        }
        else
        {
          Serial.println("Not a valid file count.");
        }
      }    
      else if (commandString.equalsIgnoreCase("HELP")){
        Serial.println(F("List of available commands:"));
        Serial.println(F("HEX         (Stream the latest log file in printable hexadecimal)"));
        Serial.println(F("BIN         (Stream the latest log file in binary format to the serial port)"));
        Serial.println(F("DEL [file-name.bin] (Delete the chosen file in the SD card)"));
        Serial.println(F("STOP        (Turn recording off)"));
        Serial.println(F("START       (Turn recording on)"));
        Serial.println(F("NEW         (Start a new log file)"));
        Serial.println(F("DF          (Show SD card capacity)"));
        Serial.println(F("LS          (List files in the SD card)"));
        Serial.println(F("LS A        (List files in the SD card with time stamp)"));
        Serial.println(F("FORMAT      (Format the SD card)"));
        Serial.println(F("BAUD        (Display current baudrate on the channels)"));
        Serial.println(F("ERRORS      (Display error count on the channels)"));
        Serial.println(F("REQUEST ON  (Turn requests on)"));
        Serial.println(F("REQUEST OFF (Turn request off)"));
        Serial.println(F("STREAM ON   (Start sending interpreted CAN Frames to the Serial port)"));
        Serial.println(F("STREAM OFF  (Stop sending interpreted CAN Frames to the Serial port)"));
        Serial.println(F("BAUDRATE    (Show the baudrate in each log file)"));
        Serial.println(F("COUNT [abc] (Set the file index to a 3 digit alphanumeric code abc)"));
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

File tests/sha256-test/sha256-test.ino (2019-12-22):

#include <sha256.h>

void setup() {
  Sha256* sha256Instance;
  BYTE hash[SHA256_BLOCK_SIZE];
  char texthash[2*SHA256_BLOCK_SIZE+1];

  Serial.begin(115200);
  delay(50);

  Serial.println("Test vector for SHA256");
  Serial.println("");
  
  BYTE text1[]="";
  const char hash_text1[] = "e3b0c44298fc1c149afbf4c8996fb92427ae41e4649b934ca495991b7852b855";
  
  BYTE text2[]="abc";
  const char hash_text2[] = "ba7816bf8f01cfea414140de5dae2223b00361a396177a9cb410ff61f20015ad";
  
  BYTE text3[]="abcdbcdecdefdefgefghfghighijhijkijkljklmklmnlmnomnopnopq";
  const char hash_text3[] = "248d6a61d20638b8e5c026930c3e6039a33ce45964ff2167f6ecedd419db06c1";
  
  BYTE text4[]="abcdefghbcdefghicdefghijdefghijkefghijklfghijklmghijklmnhijklmnoijklmnopjklmnopqklmnopqrlmnopqrsmnopqrstnopqrstu";
  const char hash_text4[] = "cf5b16a778af8380036ce59e7b0492370b249b11e8f07a51afac45037afee9d1";
  
  BYTE text5[]="This is exactly 64 bytes long, not counting the terminating byte";
  const char hash_text5[] = "ab64eff7e88e2e46165e29f2bce41826bd4c7b3552f6b382a9e7d3af47c245f8";
  
  BYTE text6[]="For this sample, this 63-byte string will be used as input data";
  const char hash_text6[] = "f08a78cbbaee082b052ae0708f32fa1e50c5c421aa772ba5dbb406a2ea6be342";
  
  BYTE text7[]="And this textual data, astonishing as it may appear, is exactly 128 bytes in length, as are both SHA-384 and SHA-512 block sizes";
  const char hash_text7[] = "0ab803344830f92089494fb635ad00d76164ad6e57012b237722df0d7ad26896";
  
  BYTE text8[]="By hashing data that is one byte less than a multiple of a hash block length (like this 127-byte string), bugs may be revealed.";
  const char hash_text8[] = "e4326d0459653d7d3514674d713e74dc3df11ed4d30b4013fd327fdb9e394c26";
  
  BYTE text9[]="The quick brown fox jumps over the lazy dog";
  const char hash_text9[] = "d7a8fbb307d7809469ca9abcb0082e4f8d5651e46d3cdb762d02d0bf37c9e592";
  
  BYTE text10[]="This test tries to use the n-block utility from the hash library and as a matter of fact we're trying to get only 128 characters";
  const char hash_text10[] = "2ce675bd3b70e104d696d1b25bf3d42b2b45cd776d4f590f210f12c44bf473d5";

  sha256Instance=new Sha256();
  sha256Instance->update(text1, strlen((const char*)text1));
  sha256Instance->final(hash);
  for(int i=0; i<SHA256_BLOCK_SIZE; ++i)
    sprintf(texthash+2*i, "%02X", hash[i]);
  Serial.print("Text to hash: ");
  Serial.println("");
  Serial.print("Hash from device: ");
  Serial.println(texthash);
  Serial.print ("Correct hash:     ");
  Serial.println (hash_text1);
  Serial.println("");
  delete sha256Instance;

  sha256Instance=new Sha256();
  sha256Instance->update(text2, strlen((const char*)text2));
  sha256Instance->final(hash);
  for(int i=0; i<SHA256_BLOCK_SIZE; ++i)
    sprintf(texthash+2*i, "%02X", hash[i]);
  Serial.print("Text to hash: ");
  Serial.println("abc");
  Serial.print("Hash from device: ");
  Serial.println(texthash);
  Serial.print ("Correct hash:     ");
  Serial.println (hash_text2);
  Serial.println("");
  delete sha256Instance;

  sha256Instance=new Sha256();
  sha256Instance->update(text3, strlen((const char*)text3));
  sha256Instance->final(hash);
  for(int i=0; i<SHA256_BLOCK_SIZE; ++i)
    sprintf(texthash+2*i, "%02X", hash[i]);
  Serial.print("Text to hash: ");
  Serial.println("abcdbcdecdefdefgefghfghighijhijkijkljklmklmnlmnomnopnopq");
  Serial.print("Hash from device: ");
  Serial.println(texthash);
  Serial.print ("Correct hash:     ");
  Serial.println (hash_text3);
  Serial.println("");
  delete sha256Instance;

  sha256Instance=new Sha256();
  sha256Instance->update(text4, strlen((const char*)text4));
  sha256Instance->final(hash);
  for(int i=0; i<SHA256_BLOCK_SIZE; ++i)
    sprintf(texthash+2*i, "%02X", hash[i]);
  Serial.print("Text to hash: ");
  Serial.println("abcdefghbcdefghicdefghijdefghijkefghijklfghijklmghijklmnhijklmnoijklmnopjklmnopqklmnopqrlmnopqrsmnopqrstnopqrstu");
  Serial.print("Hash from device: ");
  Serial.println(texthash);
  Serial.print ("Correct hash:     ");
  Serial.println (hash_text4);
  Serial.println("");
  delete sha256Instance;

  sha256Instance=new Sha256();
  sha256Instance->update(text5, strlen((const char*)text5));
  sha256Instance->final(hash);
  for(int i=0; i<SHA256_BLOCK_SIZE; ++i)
    sprintf(texthash+2*i, "%02X", hash[i]);
  Serial.print("Text to hash: ");
  Serial.println("This is exactly 64 bytes long, not counting the terminating byte");
  Serial.print("Hash from device: ");
  Serial.println(texthash);
  Serial.print ("Correct hash:     ");
  Serial.println (hash_text5);
  Serial.println("");
  delete sha256Instance;

  sha256Instance=new Sha256();
  sha256Instance->update(text6, strlen((const char*)text6));
  sha256Instance->final(hash);
  for(int i=0; i<SHA256_BLOCK_SIZE; ++i)
    sprintf(texthash+2*i, "%02X", hash[i]);
  Serial.print("Text to hash: ");
  Serial.println("For this sample, this 63-byte string will be used as input data");
  Serial.print("Hash from device: ");
  Serial.println(texthash);
  Serial.print ("Correct hash:     ");
  Serial.println (hash_text6);
  Serial.println("");
  delete sha256Instance;

  sha256Instance=new Sha256();
  sha256Instance->update(text7, strlen((const char*)text7));
  sha256Instance->final(hash);
  for(int i=0; i<SHA256_BLOCK_SIZE; ++i)
    sprintf(texthash+2*i, "%02X", hash[i]);
  Serial.print("Text to hash: ");
  Serial.println("And this textual data, astonishing as it may appear, is exactly 128 bytes in length, as are both SHA-384 and SHA-512 block sizes");
  Serial.print("Hash from device: ");
  Serial.println(texthash);
  Serial.print ("Correct hash:     ");
  Serial.println (hash_text7);
  Serial.println("");
  delete sha256Instance;

  sha256Instance=new Sha256();
  sha256Instance->update(text8, strlen((const char*)text8));
  sha256Instance->final(hash);
  for(int i=0; i<SHA256_BLOCK_SIZE; ++i)
    sprintf(texthash+2*i, "%02X", hash[i]);
  Serial.print("Text to hash: ");
  Serial.println("By hashing data that is one byte less than a multiple of a hash block length (like this 127-byte string), bugs may be revealed.");
  Serial.print("Hash from device: ");
  Serial.println(texthash);
  Serial.print ("Correct hash:     ");
  Serial.println (hash_text8);
  Serial.println("");
  delete sha256Instance;

  sha256Instance=new Sha256();
  sha256Instance->update(text9, strlen((const char*)text9));
  sha256Instance->final(hash);
  for(int i=0; i<SHA256_BLOCK_SIZE; ++i)
    sprintf(texthash+2*i, "%02X", hash[i]);
  Serial.print("Text to hash: ");
  Serial.println("The quick brown fox jumps over the lazy dog");
  Serial.print("Hash from device: ");
  Serial.println(texthash);
  Serial.print ("Correct hash:     ");
  Serial.println (hash_text9);
  Serial.println("");
  delete sha256Instance;
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

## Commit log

2019-05-19 Added Bill of materials
    [CAN Logger 3 Bill of Materials.xls]
2019-07-04 Working AES-CBC using the CAU on the Teensy 3
2019-12-13 Added sha256 libraies
    Drag the sha256 folder to Arduino library
2019-12-14 Fix Logger 3 freezing problem + clean up some files
    [CAN_Logger_with_Autobaud_and_Requests_no_CAN2_AES_CBC.ino, cau_api.h, cryptolibAESSHA.ino]
2019-12-17 Update SHA256
    Fix closing file first_buffer_sent is still true at the end, change file name for future reference, add deleted test folder back
    [CAN_Logger_with_Autobaud_and_Requests_no_CAN2_AES_CBC_SHA256.ino, cau_api.h, cryptolibAESSHA.ino]
2019-12-20 Removed the duplicate files that are normally found in the arduino libraries
    Cleaned up the defines and reduced the magic numbers too.
